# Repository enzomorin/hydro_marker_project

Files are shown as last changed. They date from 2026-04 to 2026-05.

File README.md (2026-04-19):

# hydro_marker_project

A beacon placed in small rivers to measure flooding risk, hydric stress, or normal conditions — built for the **Olympiads of Engineering Sciences**.

---

## Project overview

Each marker is a waterproof device deployed in a river. It measures water level, pressure, temperature, and battery voltage, then transmits the data via radio to a ground antenna. The antenna forwards the data to the API server, which stores it and makes it available to a dashboard and a mobile alert application.

---

## Repository structure

```
hydro_marker_project/
│
├── docs/           Documentation, source references, notes, and diagrams
│
├── app/            Dashboard application
│                   Receives data from the ground antenna, processes it,
│                   and sends it to the API. Also includes a companion app
│                   that sends alerts when a nearby marker detects potential
│                   flooding or hydric stress.
│
├── firmware/       Embedded code
│                   MCU code for the marker (sensor reading + radio transmission)
│                   and code for the ground station (receiving + forwarding frames).
│
├── hardware/       PCB design files (KiCad)
│                   Optimised circuit board for the markers — reduces electrical
│                   noise and improves efficiency.
│
├── server/         API server
│                   FastAPI + SQLite REST API that stores marker locations
│                   and all associated measurement data.
│
├── site/           Promotional website
│                   Presents the product and its specifications.
│                   Also displays live marker data and locations on a map.
│
└── tools/          Development utilities
                    Scripts and helpers that speed up development across
                    all parts of the project.
```

---

## Quick start

To run the API server locally, see [`server/README.md`](server/README.md).

---

## Tech used overview

| Component | Technology |
|---|---|
| API server | Python, FastAPI, SQLite |
| Firmware | C++ (MCU), PlatfromIO IDE |
| PCB design | KiCad |
| Dashboard | Electron, Javascript |
| Website | HTML, CSS, Javascript |

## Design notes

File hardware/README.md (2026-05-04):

# HydroVinci — PCB Design

> Compact, low-power PCB for the HydroVinci marker system. Designed in KiCad 10, built around the Seeed XIAO nRF52840 Plus.

---

## Table of Contents

- [Overview](#overview)
- [Hardware Summary](#hardware-summary)
- [Prerequisites](#prerequisites)
- [Opening the Project](#opening-the-project)
- [Manufacturing](#manufacturing)
- [Design Notes](#design-notes)
- [Tech used](#tech-used)

---

## Overview

This repository contains the full KiCad design files for the HydroVinci PCB. The board integrates all electronics required by the marker into a single compact PCB, replacing a wired prototype with a manufacturable solution.

The design targets low quiescent current for battery-powered field deployment, with switchable power rails for each peripheral.

---

## Hardware Summary

| Component | Description |
|---|---|
| MCU | Seeed XIAO nRF52840 Plus (BLE 5.0, nRF52840) |
| Power | LiPo battery input, 12V boost (Adafruit TPS61040) |
| Pressure sensor | DFRobot KIT0139 submersible 4-20mA, converted via SEN0262 |
| Environmental | AZ-Delivery GY-BME280 (temperature, humidity, pressure) |
| Hall effect | Digital Hall sensor via BSS84 high-side switch |
| Data logging | SparkFun OpenLog DEV-13712 (microSD, UART) |
| RF | CC1101 sub-GHz radio module |
| Power switching | BSS138 + BSS84 MOSFET pairs (3.3V and 12V rails) |
| Indicators | Passive buzzer, 2× tactile buttons |

---

## Prerequisites

- [KiCad](https://www.kicad.org/) `>= 10.0`

No additional dependencies. All custom symbols and footprints are included in the repository under `src/PCB/libraries/`.

---

## Opening the Project

1. Clone the repository
   ```bash
   git clone https://github.com/your-org/hydrovinci-pcb.git
   ```

2. Open KiCad and select **File → Open Project**

3. Navigate to `src/PCB/main_pcb.kicad_pro` and open it

From the KiCad project manager you can then open:
- **Schematic Editor** — for the electrical design and component wiring
- **PCB Editor** — for the physical board layout and copper routing

---

## Manufacturing

Gerber files are required to manufacture the board. To generate them from KiCad:

1. Open the PCB Editor (`main_pcb.kicad_pcb`)
2. Go to **File → Fabrication Outputs → Gerbers**
3. Select all required layers and export

The generated Gerbers can be uploaded directly to:
- [JLCPCB](https://jlcpcb.com) — recommended for low-cost prototyping
- [PCBway](https://www.pcbway.com) — recommended for higher quantities

> **Recommended specs:** 2-layer, 1oz copper.

---

## Design Notes

- All GPIO outputs include 100Ω series resistors for noise immunity
- The 12V rail (KIT0139 sensor loop) is switched via a BSS138 + BSS84 MOSFET pair — Vgs is clamped to −6V by R20 to stay within BSS84 absolute maximum ratings
- The EN pin of the boost converter is pulled to GND via R7 (100kΩ) to ensure the 12V rail is off during boot and reset
- The SEN0262 output capacitor (C14) must be rated ≥ 25V (ceramic X5R/X7R, 0805)
- I2C pull-ups R3/R4 (10kΩ) may be omitted if the BME280 module already includes them

---

## Tech used



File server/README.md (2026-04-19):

# HydroVinci — API Server

**HydroVinci API server** is an **API** secured by simple authentification system key. The **API** is based with **FastAPI** and deployed with **uvicorn** that handle the logic to store in a **SQLite database** the different markers around the world with his measure data associated:

---
 
## Table of contents
 
- [Overview](#overview)
- [Prerequisites](#prerequisites)
- [Setup](#setup)
- [Running the server](#running-the-server)
- [Authentication](#authentication)
- [Endpoints — Markers](#endpoints--markers)
- [Endpoints — Readings](#endpoints--readings)
- [Database fields](#database-fields)
- [Tech stack](#tech-stack)

---

## Overview
 
Each physical marker deployed in a river communicates sensor data to a ground antenna. The antenna receive the radio frames and pushes them to this API. The API stores everything in a local SQLite database and exposes endpoints to manage, and monitor all markers and their measurements.
 
---
 
## Prerequisites
 
- Python `>= 3.12`
- `pip`
- `git`
- `pyenv` recommended for managing Python versions on Fedora / Linux :)
---
 
## Setup
 
**1. Clone the repository**
 
```bash
git clone https://github.com/enzomorin/hydro_marker_project.git

cd hydro_marker_project/server
```
 
**2. Install Python 3.12**
 
```bash
pyenv install 3.12
pyenv local 3.12
```
 
**3. Create and activate a virtual environment**
 
```bash
virtualenv .venv             # Fedora only
python -m venv .venv
 
source .venv/bin/activate    # Linux / macOS
.venv\Scripts\activate       # Windows
```
 
**4. Install dependencies**
 
```bash
pip install -r requirements.txt
```
 
**5. Configure environment variables**
 
```bash
cp .env.example .env
```
 
Open `.env` and replace the placeholder values:
 
```env
DB_PATH=./data/markers.db
 
API_KEY=your_antenna_secret_key
ADMIN_KEY=your_admin_secret_key
 
APP_NAME=River Monitor API
DEBUG=true
```
 
> **Never commit `.env` to git** — it contains your secrets. It is already listed in `.gitignore`.
 
---
 
## Running the server
 
**Option 1 — Direct (recommended for development)**
 
```bash
python src/main.py
```
 
**Option 2 — Uvicorn directly**
 
```bash
python -m uvicorn src.main:app --host 127.0.0.1 --port 8000 --reload
```
 
The server is accessible at: `http://127.0.0.1:8000`
 
Interactive API documentation: `http://127.0.0.1:8000/docs`
 
---
 
## Authentication
 
Every request must include an `X-Api-Key` header. There are two access levels:
 
| Key | Header value | Access |
|---|---|---|
| Antenna key (`API_KEY`) | `X-Api-Key: your_antenna_key` | Read data + push readings |
| Admin key (`ADMIN_KEY`) | `X-Api-Key: your_admin_key` | Full access |
 
Implemente two key is very useful, if an attacker find a way to hack the ground station and extract the antenna_key, he can only read and push data and cannot delete markers and measurements.
 
```bash
# Example with antenna key
curl -H "X-Api-Key: your_antenna_key" http://127.0.0.1:8000/api/v1/markers/
 
# Example with admin key
curl -H "X-Api-Key: your_admin_key" http://127.0.0.1:8000/api/v1/markers/
```
 
---
 
## Endpoints — Markers
 
### `GET /api/v1/markers/`
Return the list of all active markers.
 
```bash
curl -H "X-Api-Key: your_antenna_key" \
  http://127.0.0.1:8000/api/v1/markers/
```
 
Add `?include_deleted=true` to also return soft-deleted markers.
 
---
 
### `GET /api/v1/markers/{marker_id}`
Return one specific marker by its ID.
 
```bash
curl -H "X-Api-Key: your_antenna_key" \
  http://127.0.0.1:8000/api/v1/markers/1
```
 
---
 
### `POST /api/v1/markers/` — Admin only
Register a new physical marker.
 
```bash
curl -X POST \
  -H "X-Api-Key: your_admin_key" \
  -H "Content-Type: application/json" \
  -d '{"name": "La-loire", "location": "48.8566,2.3522"}' \
  http://127.0.0.1:8000/api/v1/markers/
```
 
| Field | Type | Required | Default | Description |
|---|---|---|---|---|
| `name` | string | ✓ | — | Human-readable label |
| `location` | string | ✓ | — | GPS coordinates as `"lat,lon"` |
| `radius` | integer | | `500` | measure radius in metres |
| `is_active` | boolean | | `true` | Whether the marker is receiving data |
 
---
 
### `PATCH /api/v1/markers/{marker_id}` — Admin only
Update one or more fields of an existing marker. Only send the fields you want to change.
 
```bash
curl -X PATCH \
  -H "X-Api-Key: your_admin_key" \
  -H "Content-Type: application/json" \
  -d '{"is_active": false}' \
  http://127.0.0.1:8000/api/v1/markers/1
```
 
---
 
### `DELETE /api/v1/markers/{marker_id}` — Admin only
Move a marker to the trash (soft delete — recoverable).
 
```bash
curl -X DELETE \
  -H "X-Api-Key: your_admin_key" \
  http://127.0.0.1:8000/api/v1/markers/1
```
 
---
 
### `PUT /api/v1/markers/{marker_id}/restore` — Admin only
Recover a soft-deleted marker from the trash.
 
```bash
curl -X PUT \
  -H "X-Api-Key: your_admin_key" \
  http://127.0.0.1:8000/api/v1/markers/1/restore
```
 
---
 
### `DELETE /api/v1/markers/{marker_id}/purge` — Admin only
Permanently delete a marker and **all its readings**. This is irreversible.
 
```bash
curl -X DELETE \
  -H "X-Api-Key: your_admin_key" \
  http://127.0.0.1:8000/api/v1/markers/1/purge
```
 
---
 
## Endpoints — Readings
 
### `POST /api/v1/readings/`
Push a single sensor frame from the antenna.
 
```bash
curl -X POST \
  -H "X-Api-Key: your_antenna_key" \
  -H "Content-Type: application/json" \
  -d '{
    "marker_id": 1,
    "water_level": 1.42,
    "pressure": 1013.0,
    "temperature": 14.5,
    "battery": 3.8
  }' \
  http://127.0.0.1:8000/api/v1/readings/
```
 
| Field | Type | Required | Description |
|---|---|---|---|
| `marker_id` | integer | ✓ | ID of the marker that sent this frame |
| `recorded_at` | datetime | | When the marker took the measurement (defaults to now) |
| `water_level` | float | | Water level in metres |
| `pressure` | float | | Atmospheric pressure in hPa |
| `temperature` | float | | Water temperature in °C |
| `battery` | float | | Battery voltage in V |
| `raw_payload` | string | | Original RF frame bytes, for debugging |
 
All sensor fields are optional — a partial frame is still stored.
 
---
 
### `POST /api/v1/readings/batch`
Push multiple frames in one request. Useful when the antenna was offline and has buffered frames. Either all frames are saved or none are (atomic transaction).
 
```bash
curl -X POST \
  -H "X-Api-Key: your_antenna_key" \
  -H "Content-Type: application/json" \
  -d '[
    {"marker_id": 1, "water_level": 1.40, "temperature": 14.2},
    {"marker_id": 1, "water_level": 1.41, "temperature": 14.3},
    {"marker_id": 1, "water_level": 1.42, "temperature": 14.5}
  ]' \
  http://127.0.0.1:8000/api/v1/readings/batch
```
 
---
 
### `GET /api/v1/readings/latest?marker_id={id}`
Return the most recent reading for a specific marker. This is the endpoint to call for a live dashboard tile.
 
```bash
curl -H "X-Api-Key: your_antenna__key" \
  "http://127.0.0.1:8000/api/v1/readings/latest?marker_id=1"
```
 
---
 
### `GET /api/v1/readings/`
Return a paginated list of readings with optional filters.
 
| Parameter | Type | Description |
|---|---|---|
| `marker_id` | integer | Filter by marker |
| `since` | datetime | Lower bound on measurement time |
| `until` | datetime | Upper bound on measurement time |
| `limit` | integer (1–1000) | Max rows to return, default `100` |
| `offset` | integer | Rows to skip, for pagination |
 
```bash
# All readings for marker 1
curl -H "X-Api-Key: your_antenna_key" \
  "http://127.0.0.1:8000/api/v1/readings/?marker_id=1"
 
# Page 2 (rows 101–200)
curl -H "X-Api-Key: your_antenna_key" \
  "http://127.0.0.1:8000/api/v1/readings/?marker_id=1&limit=100&offset=100"
```
 
---
 
### `GET /api/v1/readings/{reading_id}`
Return one specific reading by its numeric ID.
 
```bash
curl -H "X-Api-Key: your_antenna_key" \
  http://127.0.0.1:8000/api/v1/readings/42
```
 
---
 
### `DELETE /api/v1/readings/{reading_id}` — Admin only
Permanently delete one reading. Use this to remove bad data from a faulty sensor or a test transmission.
 
```bash
curl -X DELETE \
  -H "X-Api-Key: your_admin_key" \
  http://127.0.0.1:8000/api/v1/readings/42
```
 
---
 
## Database fields
 
### `markers` table
 
| Field | Type | Description |
|---|---|---|
| `id` | integer | Auto-assigned primary key |
| `name` | string | Human-readable label |
| `location` | string | GPS coordinates as `"lat,lon"` |
| `radius` | integer | Alert radius in metres |
| `is_active` | boolean | Whether the marker is currently active |
| `is_deleted` | boolean | Soft-delete flag |
| `created_at` | datetime | UTC timestamp of registration |
 
### `readings` table
 
| Field | Type | Description |
|---|---|---|
| `id` | integer | Auto-assigned primary key |
| `marker_id` | integer | Foreign key → `markers.id` |
| `recorded_at` | datetime | When the marker took the measurement |
| `received_at` | datetime | When the server received the frame |
| `water_level` | float | Water level in metres |
| `pressure` | float | Atmospheric pressure in hPa |
| `temperature` | float | Water temperature in °C |
| `battery` | float | Battery voltage in V |
| `raw_payload` | string | Original RF frame for debugging |
 
---
 
## Tech used
 






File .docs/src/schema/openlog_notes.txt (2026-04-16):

et bien peut tu vérifier que le openlog en sleep consomme moins que 2mA je pense qu'il consome moins et aussi est ce que des résistance, condensateur et bobine consomme un petit peu de courant aussi ?

Très bonne question — et tu as raison de remettre ça en doute, parce que 2 mA en veille pour un OpenLog, c’est énorme pour un projet basse conso.

🔎 1) Conso réelle du OpenLog en veille

👉 Pour le SparkFun OpenLog (ATmega328 + microSD) :

📊 Valeurs typiques (issues des datasheets + retours utilisateurs)
Actif (écriture SD) : ~20–25 mA ✅ (cohérent avec ton tableau)
Idle (allumé, rien ne fait) : ~10–15 mA ❗
Sleep (optimisé) :
ATmega328 seul : ~5–50 µA
MAIS carte OpenLog complète :
régulateur
LED
carte SD

👉 En pratique :

Carte SD seule : ~100 µA à plusieurs mA selon état 😬
Régulateur + LED → fuite continue
⚠️ Conclusion réaliste

👉 Un OpenLog “stock” :

❌ pas conçu pour ultra low power
✔️ conso typique en veille réelle :
👉 ~1 mA à 5 mA (parfois pire)

👉 Donc :
💬 Ton “2 mA” est plutôt crédible, voire optimiste.

🛠️ Si tu veux vraiment réduire :
couper alimentation via transistor/MOSFET ✅ (meilleure solution)
enlever LED
utiliser une SD low-power
ou remplacer par autre chose (ex: FRAM)
⚡ 2) Est-ce que résistances, condensateurs, bobines consomment ?

👉 Réponse courte :
✔️ oui, mais pas toujours de la même façon

🔌 Résistance

👉 Consomme TOUJOURS si courant passe

Formule :
👉 I = V / R

Exemple :

3.3V avec résistance 10kΩ
→ 3.3 / 10000 = 0.33 mA

⚠️ Donc :

pull-up / pull-down mal choisis → grosse perte !
⚡ Condensateur

👉 Ne consomme pas en régime stable

consomme uniquement pendant charge/décharge
fuite très faible (µA ou moins)

✔️ Donc négligeable dans ton cas

🌀 Bobine (inductance)

👉 Idem :

pas de conso directe
MAIS :
résistance interne (R série)
pertes dans convertisseurs (buck/boost)
⚠️ Les VRAIS pièges en basse conso

Ce qui consomme vraiment sans qu’on s’en rende compte :

🔴 1. Régulateur de tension
peut consommer 10 µA à 1 mA
👉 énorme sur 3 mois
🔴 2. LED
1 LED = 1 à 5 mA 😬
🔴 3. Pull-up trop faibles
ex : 1kΩ → gaspillage massif
🔴 4. Modules non coupés
capteurs ou radio “en veille” → souvent trompeur
✅ Conclusion claire

👉 OpenLog :

❌ pas basse conso
✔️ ton estimation ~2 mA est crédible

👉 Composants passifs :

résistance → OUI consomme
condensateur → quasi rien
bobine → indirect
💡 Reco pour ton projet

👉 Pour tenir 3 mois facilement :

❌ éviter OpenLog alimenté en continu
✔️ couper alimentation modules (MOSFET)
✔️ viser conso sleep < 10 µA total
✔️ utiliser résistances ≥ 100kΩ si possible

Si tu veux, je peux te faire :
👉 un schéma optimisé ultra low power (avec coupure des modules)
👉 ou recalculer autonomie avec TON montage exact (très utile)

qu'elles sont tout les types de transistor et leur usage dans un cas précis et aussi mon openlog je peux le couper avec un MOSFET mais avec le serial et tout et l'inisialisation de la carte sd à l'allumage sa ne va pas faire n'importe quoi ?

Bonne question — tu touches exactement aux deux points clés : choix du transistor et coupure propre d’un module comme l’OpenLog. On va faire ça clairement et sans blabla inutile.

🔌 1) Les types de transistors (et quand les utiliser)
🧱 1. BJT (bipolaires)
Types :
NPN
PNP
👉 Usage typique :
Commutation simple
Amplification analogique
✔️ Exemple concret :
Allumer une LED
Piloter un petit module
⚠️ Inconvénients :
Consomme du courant en base
Moins efficace que MOSFET

👉 En basse conso → pas idéal

⚡ 2. MOSFET (les plus importants pour toi)
Types :
N-MOS (canal N)
P-MOS (canal P)
🔵 N-MOS

👉 Sert à couper la masse (low-side switch)

✔️ Avantages :
Très efficace
Facile à piloter (GPIO)
❌ Problème :
Le module reste relié au +
→ peut créer des comportements bizarres (retours par IO)
🔴 P-MOS

👉 Sert à couper le + (high-side switch)

✔️ Avantages :
Coupe complètement l’alimentation
Propre pour modules (comme OpenLog)
❌ Plus complexe à piloter
💡 Conclusion pratique :

👉 Pour ton cas :

❌ N-MOS → risqué avec UART
✔️ P-MOS → meilleur choix
🧠 3. Autres types (moins utiles ici)
🟡 Darlington
Très fort gain
Mais chute de tension élevée
👉 pas adapté basse conso
🟢 IGBT
Puissance (moteurs, industrie)
👉 inutile ici
⚠️ 2) Couper l’OpenLog avec MOSFET + UART

👉 Ta question est excellente :

“est-ce que ça va faire n’importe quoi avec le serial et la SD ?”

👉 Réponse courte :

✔️ NON, si c’est bien fait
❌ OUI, si mal câblé

🚨 Les vrais problèmes possibles
🔴 1. Retour de courant par UART

Quand OpenLog est OFF :

TX/RX peuvent alimenter la carte par les pins 😬

👉 Résultat :

faux démarrage
conso fantôme
comportement instable
🔴 2. Initialisation SD

À chaque ON :

la carte SD redémarre
OpenLog reboot

👉 Donc :
✔️ prévoir un délai (~100–500 ms)
✔️ réinitialiser la communication série

✅ Solution propre (recommandée)
✔️ 1. Utiliser un P-MOS (high-side)

Schéma logique :

Batterie + ── P-MOS ── OpenLog VCC
                |
              GPIO
✔️ 2. Protéger les lignes UART
Méthodes :
🟢 Option A (simple)
mettre résistance série (~10k) sur TX/RX
🟢 Option B (propre)
mettre MOSFET ou buffer tri-state
🟢 Option C (très simple et efficace)

👉 Mettre les GPIO en INPUT quand OpenLog est OFF

✔️ 3. Séquence logicielle

Quand tu veux écrire :

Activer MOSFET → ON
Attendre ~200 ms
Init Serial
Envoyer données
Attendre fin écriture (~50–100 ms)
Couper MOSFET
🧪 Est-ce que ça marche en pratique ?

👉 Oui, c’est une technique ultra classique en IoT basse conso

Utilisée pour :

cartes SD
capteurs gourmands
modules radio
⚠️ Point critique

👉 OpenLog n’est pas fait pour ça à la base

Donc :

parfois instable au boot
dépend de la carte SD
💡 Alternative BEAUCOUP plus propre

Si tu veux un système fiable :

✔️ Option 1
écrire directement depuis le nRF52840 sur SD
✔️ Option 2
utiliser mémoire FRAM (ultra basse conso)
✅ Conclusion

👉 Transistors :

MOSFET > BJT pour ton projet
P-MOS = meilleur choix pour couper alimentation

👉 OpenLog :

✔️ possible de le couper
⚠️ attention UART + timing
✔️ ajouter résistances ou mettre GPIO en entrée

Si tu veux, je peux :
👉 te dessiner un schéma exact (propre et safe)
👉 ou te donner un montage ultra optimisé pour tenir 1 an+ de batterie

parle moi plus en détail des option B C et D

Parfait, là on rentre dans le concret 👍
Je vais détailler proprement les solutions pour éviter les retours de courant via l’UART quand tu coupes l’OpenLog.

⚠️ Rappel rapide du problème

Quand ton OpenLog est OFF mais relié au microcontrôleur :

les broches TX/RX peuvent injecter du courant
→ le module peut se “semi-alimenter”
→ bugs + conso fantôme 😬
🟢 Option B — Buffer / Tri-state (solution propre)
💡 Principe

Tu interposes un composant entre MCU et OpenLog :

👉 Quand OpenLog OFF → lignes déconnectées électriquement

🔧 Composants typiques
74HC125
74LVC1T45
⚙️ Fonctionnement
Le buffer a une entrée “enable”
Quand désactivé → sortie = haute impédance (comme si débranché)
✔️ Avantages
Très propre électriquement
Aucun retour de courant
Stable à 100%
❌ Inconvénients
Ajoute un composant
Un peu plus complexe
🧠 Quand utiliser

👉 Projet sérieux / production / basse conso optimisée

🟢 Option C — GPIO en mode INPUT (solution simple et efficace)
💡 Principe

Quand OpenLog est OFF :

👉 tu mets :

TX → INPUT
RX → INPUT
⚙️ Pourquoi ça marche
Une entrée = très haute impédance
Donc presque aucun courant ne passe
✔️ Avantages
Ultra simple
Pas de composant
Très utilisé en pratique
❌ Limites
Pas aussi “parfait” qu’un buffer
Peut rester micro-fuites (mais souvent négligeables)
🧠 Exemple de séquence
// Avant extinction OpenLog
pinMode(TX, INPUT);
pinMode(RX, INPUT);

// couper MOSFET

Puis au réveil :

// rallumer OpenLog
// attendre 200 ms

pinMode(TX, OUTPUT);
pinMode(RX, INPUT);
Serial.begin(9600);
🧠 Quand utiliser

👉 90% des projets low power → suffisant

🟢 Option D — Résistances série (solution “semi-propre”)
💡 Principe

Tu ajoutes une résistance sur chaque ligne UART :

4.7kΩ à 10kΩ typiquement
⚙️ Ce que ça fait
limite le courant si retour
évite d’alimenter fortement le module
✔️ Avantages
Très simple
Pas cher
améliore déjà beaucoup la situation
❌ Inconvénients
Ne bloque PAS totalement le courant
juste une limitation
🧠 Exemple
MCU TX ──[10k]── RX OpenLog
MCU RX ──[10k]── TX OpenLog
🧠 Quand utiliser

👉 en complément d’une autre méthode

🏆 Comparaison rapide
Solution	Efficacité	Complexité	Recommandé
Buffer (B)	⭐⭐⭐⭐⭐	Moyen	Projets critiques
GPIO INPUT (C)	⭐⭐⭐⭐	Très simple	✅ meilleur choix
Résistance (D)	⭐⭐⭐	Très simple	En complément
💡 Ce que je te recommande (concret)

👉 Pour TON projet :

✔️ Option C + D combinées

GPIO en INPUT quand OFF
résistances 10k sur TX/RX

👉 = simple + fiable + basse conso

⚠️ Petit détail important

Même avec tout ça :
👉 toujours prévoir :

délai après allumage (200–500 ms)
réinitialisation série
parfois 1er message ignoré
✅ Conclusion
Option B → parfaite mais plus complexe
Option C → meilleur compromis
Option D → sécurité en plus

👉 combo C + D = 🔥 parfait pour toi

🔧 🎯 OBJECTIF

Passer de :

4.8 kbps → 2.4 kbps
garder BW ~58 kHz
garder GFSK
ajuster deviation

👉 Sur CC1101 ça joue ici :

MDMCFG4
MDMCFG3
DEVIATN

(Car data rate = combinaison MDMCFG4/3 )

🧩 ✅ MODIFICATIONS À FAIRE
🔵 1. DATA RATE (LE PLUS IMPORTANT)
❌ TON CODE ACTUEL
writeReg(Config::MDMCFG4,  0xF5);
writeReg(Config::MDMCFG3,  0x83); // ~4.8 kbps
✅ NOUVELLE CONFIG (≈ 2.4 kbps)
writeReg(Config::MDMCFG4,  0xF6);
writeReg(Config::MDMCFG3,  0x83);
🔵 2. DEVIATION (petit ajustement)
❌ actuel
writeReg(Config::DEVIATN,  0x35); // ~25 kHz
✅ recommandé (un peu plus propre pour 2.4 kbps)
writeReg(Config::DEVIATN,  0x34); // ~20–22 kHz
🟢 3. LE RESTE → TU NE TOUCHES PAS

✔️ déjà optimal :

writeReg(Config::MDMCFG2,  0x13); // GFSK ✔️
writeReg(Config::MDMCFG1,  0x22); // OK
writeReg(Config::MDMCFG0,  0xF8); // spacing OK

✔️ BW ~58 kHz déjà bon

🧠 💡 EXPLICATION CLAIRE
📉 1. Pourquoi MDMCFG4 change ?

Dans CC1101 :

MDMCFG4 → exponent (DRATE_E)
MDMCFG3 → mantisse (DRATE_M)

👉 formule interne :

𝑅
𝑑
𝑎
𝑡
𝑎
=
(
256
+
𝐷
𝑅
𝐴
𝑇
𝐸
𝑀
)
⋅
2
𝐷
𝑅
𝐴
𝑇
𝐸
𝐸
⋅
𝑓
𝑜
𝑠
𝑐
2
28
R
data

=
2
28
(256+DRATE
M

)⋅2
DRATE
E

⋅f
osc

👉 donc :

passer 0xF5 → 0xF6
➡️ divise presque par 2 le débit
📡 2. Pourquoi c’est mieux

👉 ↓ débit = ↑ sensibilité

4.8 kbps → ~ -112 dBm
2.4 kbps → ~ -115 dBm

➡️ +3 dB ≈ +40% portée

📶 3. Pourquoi ajuster la déviation

👉 règle RF :

deviation ≈ data_rate × 8 à 10

4.8 kbps → ~25 kHz ✔️
2.4 kbps → ~20 kHz mieux

➡️ meilleure stabilité + moins d’erreurs

⚡ IMPACT RÉEL
Paramètre	Avant	Après
Débit	4.8 kbps	2.4 kbps
Sensibilité	-112 dBm	-115 dBm
Portée	~400 m	~700 m
Conso	identique	identique
🚀 BONUS (très important)

👉 avec ton usage (1 envoi toutes 12h) :

➡️ temps TX double
➡️ MAIS énergie ≈ identique
➡️ portée ↑ énormément

👉 donc c’est un upgrade gratuit

🧾 VERSION FINALE (copier-coller)
// Modem config optimisé longue portée
writeReg(Config::MDMCFG4,  0xF6); // ↓ data rate
writeReg(Config::MDMCFG3,  0x83); // mantisse inchangée
writeReg(Config::MDMCFG2,  0x13); // GFSK
writeReg(Config::MDMCFG1,  0x22);
writeReg(Config::MDMCFG0,  0xF8);

// Deviation ajustée
writeReg(Config::DEVIATN,  0x34);
🧠 CONCLUSION

👉 tu viens de gagner :

portée ++
robustesse ++
sans coût batterie

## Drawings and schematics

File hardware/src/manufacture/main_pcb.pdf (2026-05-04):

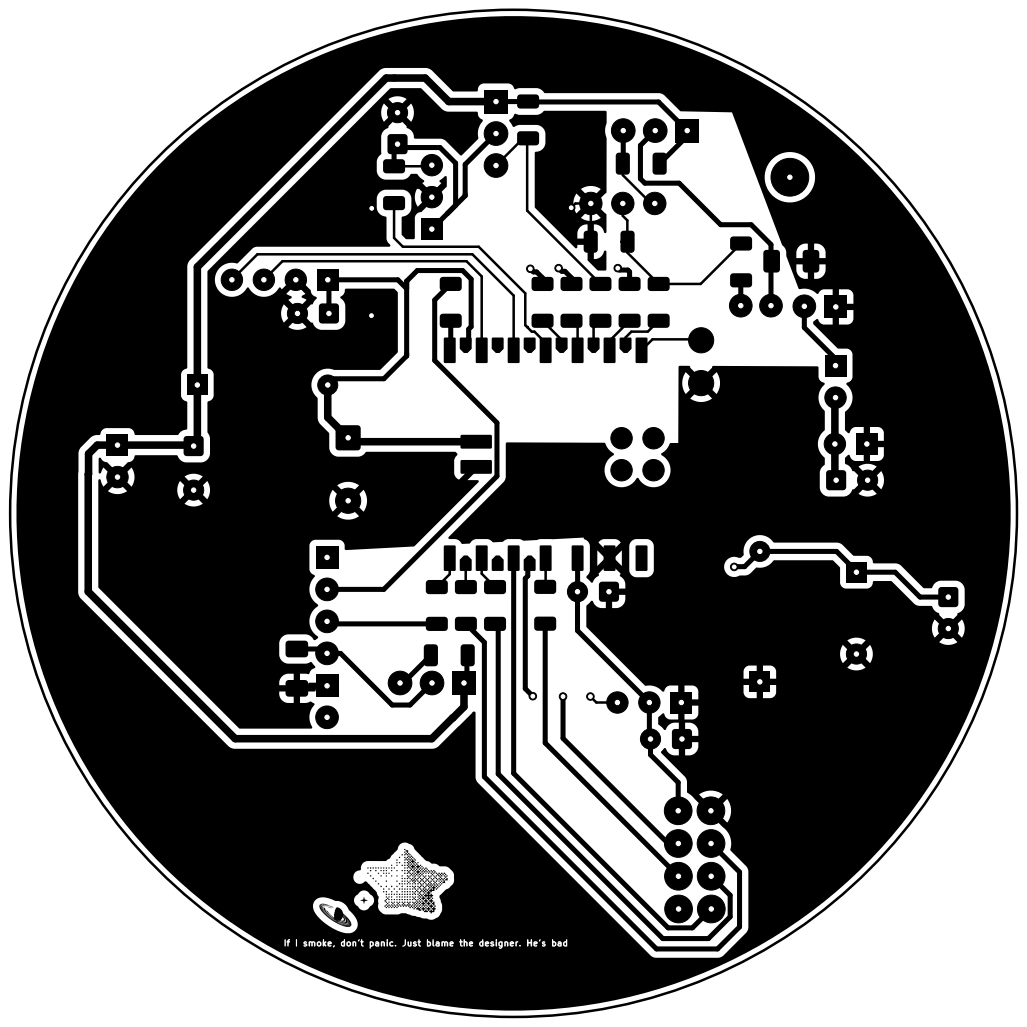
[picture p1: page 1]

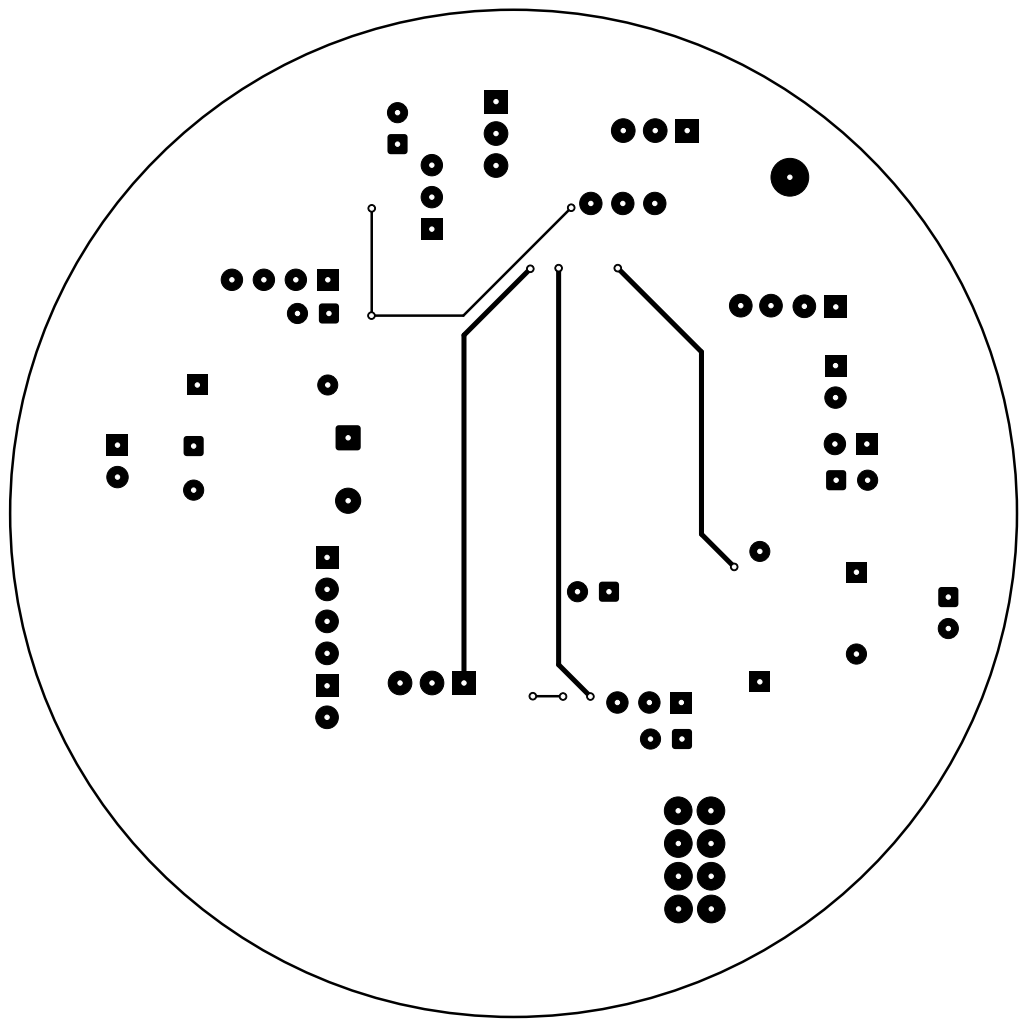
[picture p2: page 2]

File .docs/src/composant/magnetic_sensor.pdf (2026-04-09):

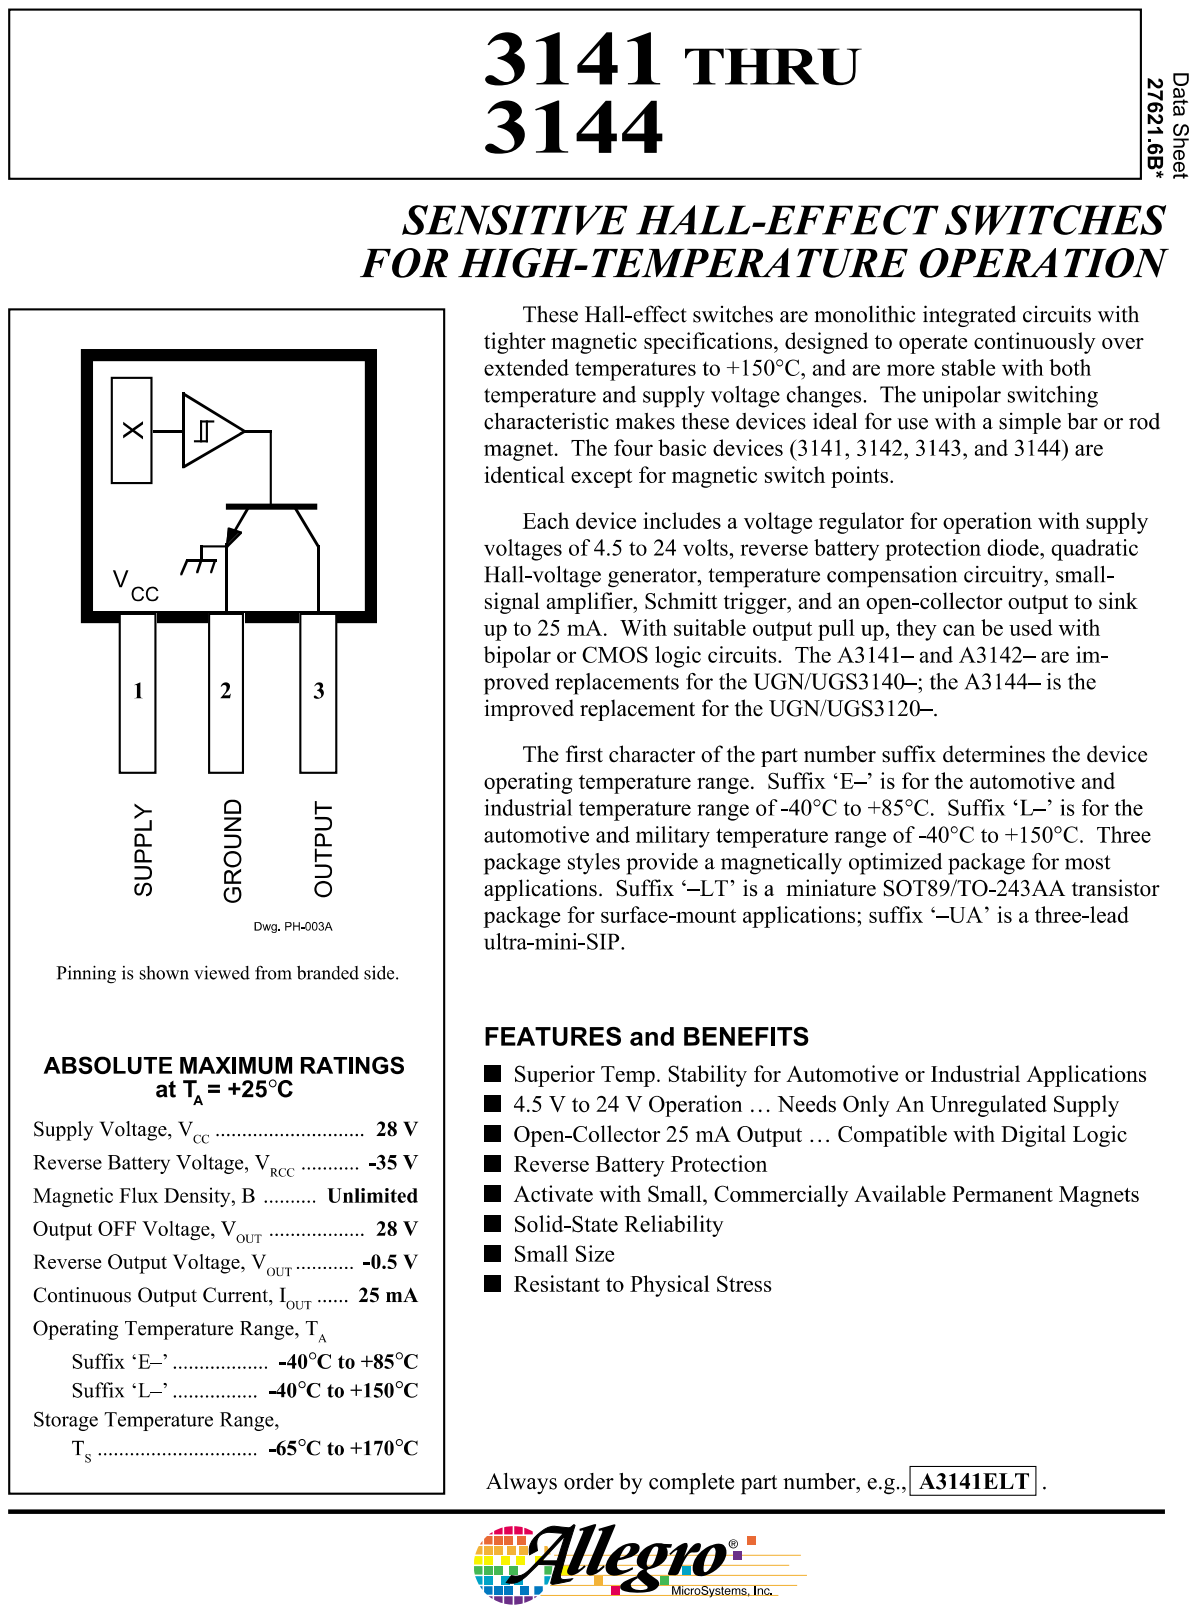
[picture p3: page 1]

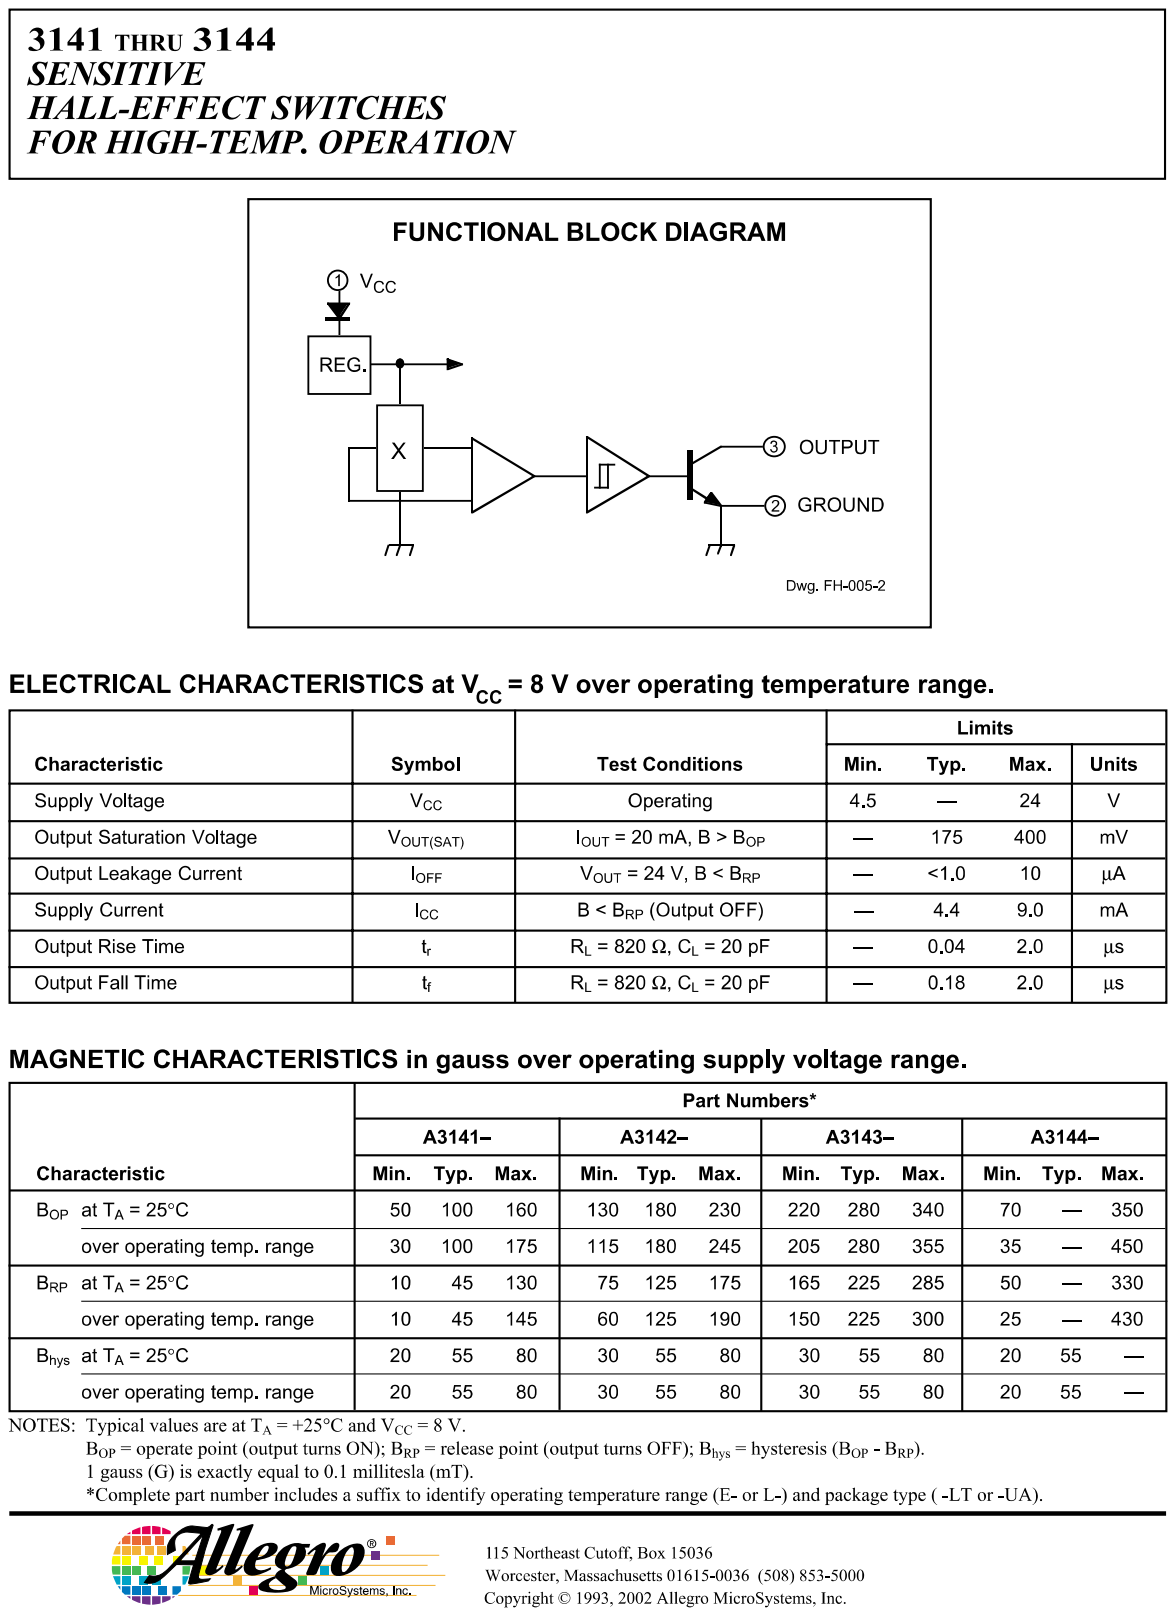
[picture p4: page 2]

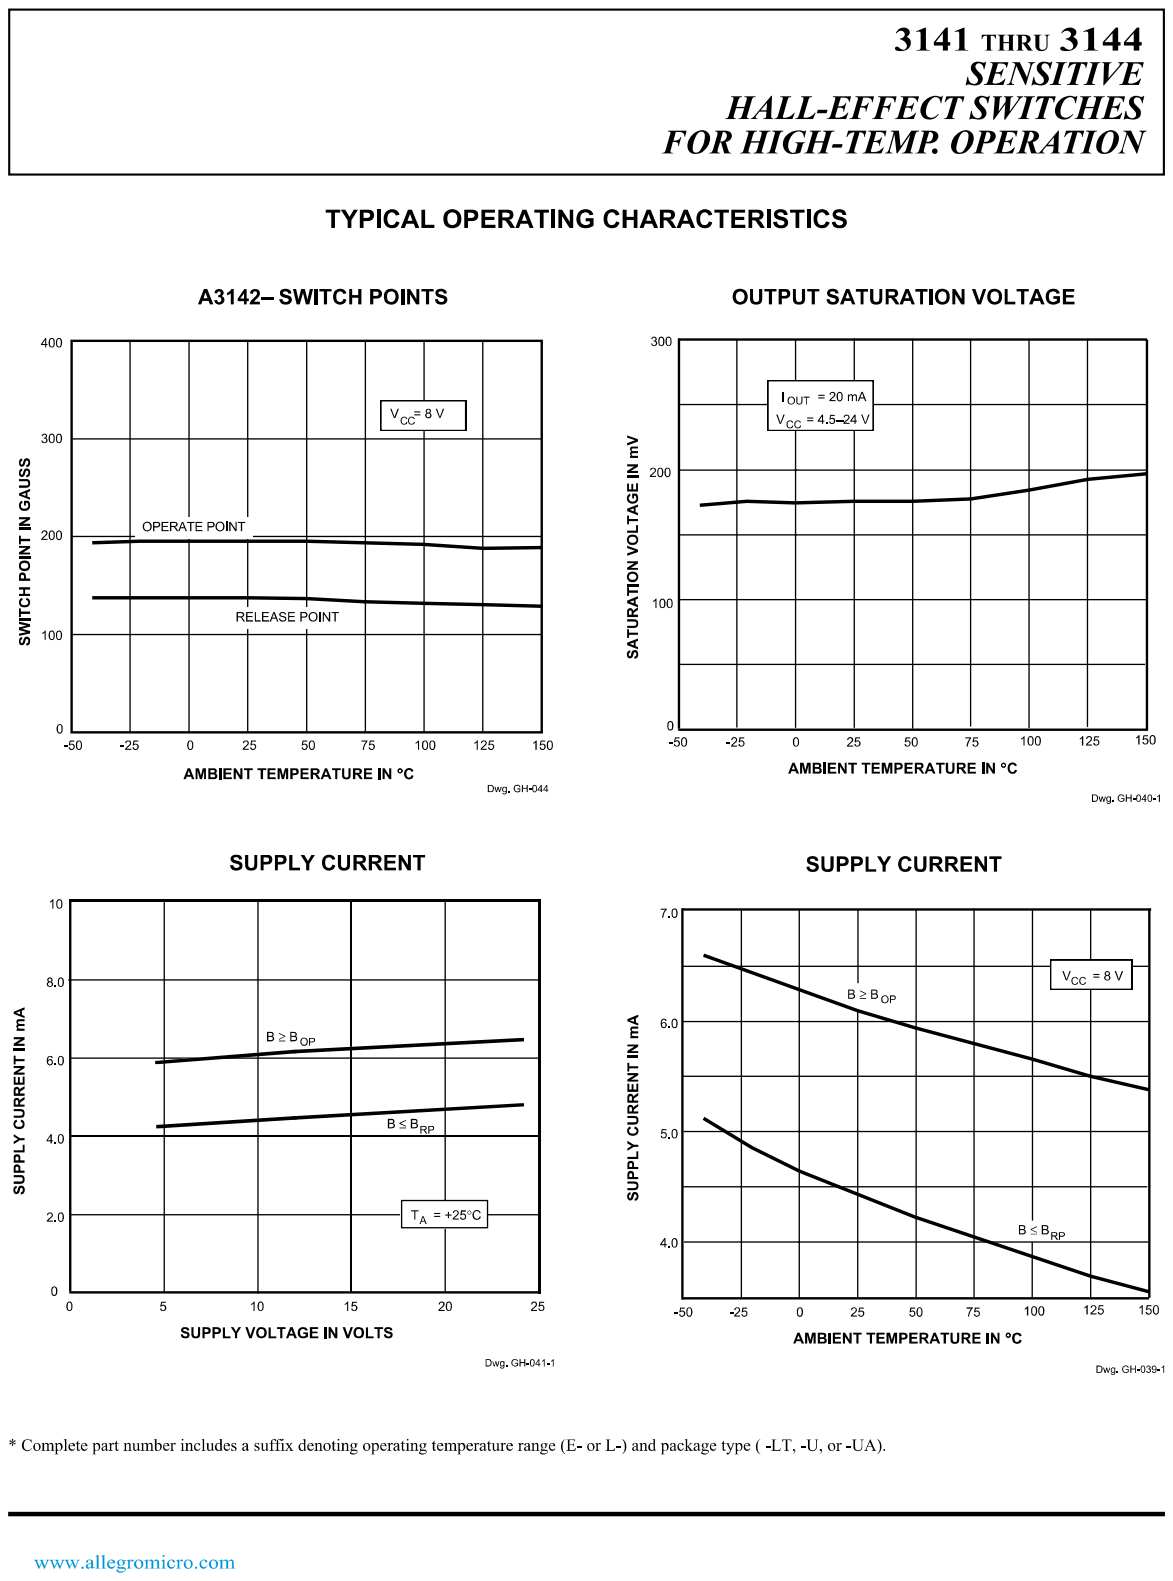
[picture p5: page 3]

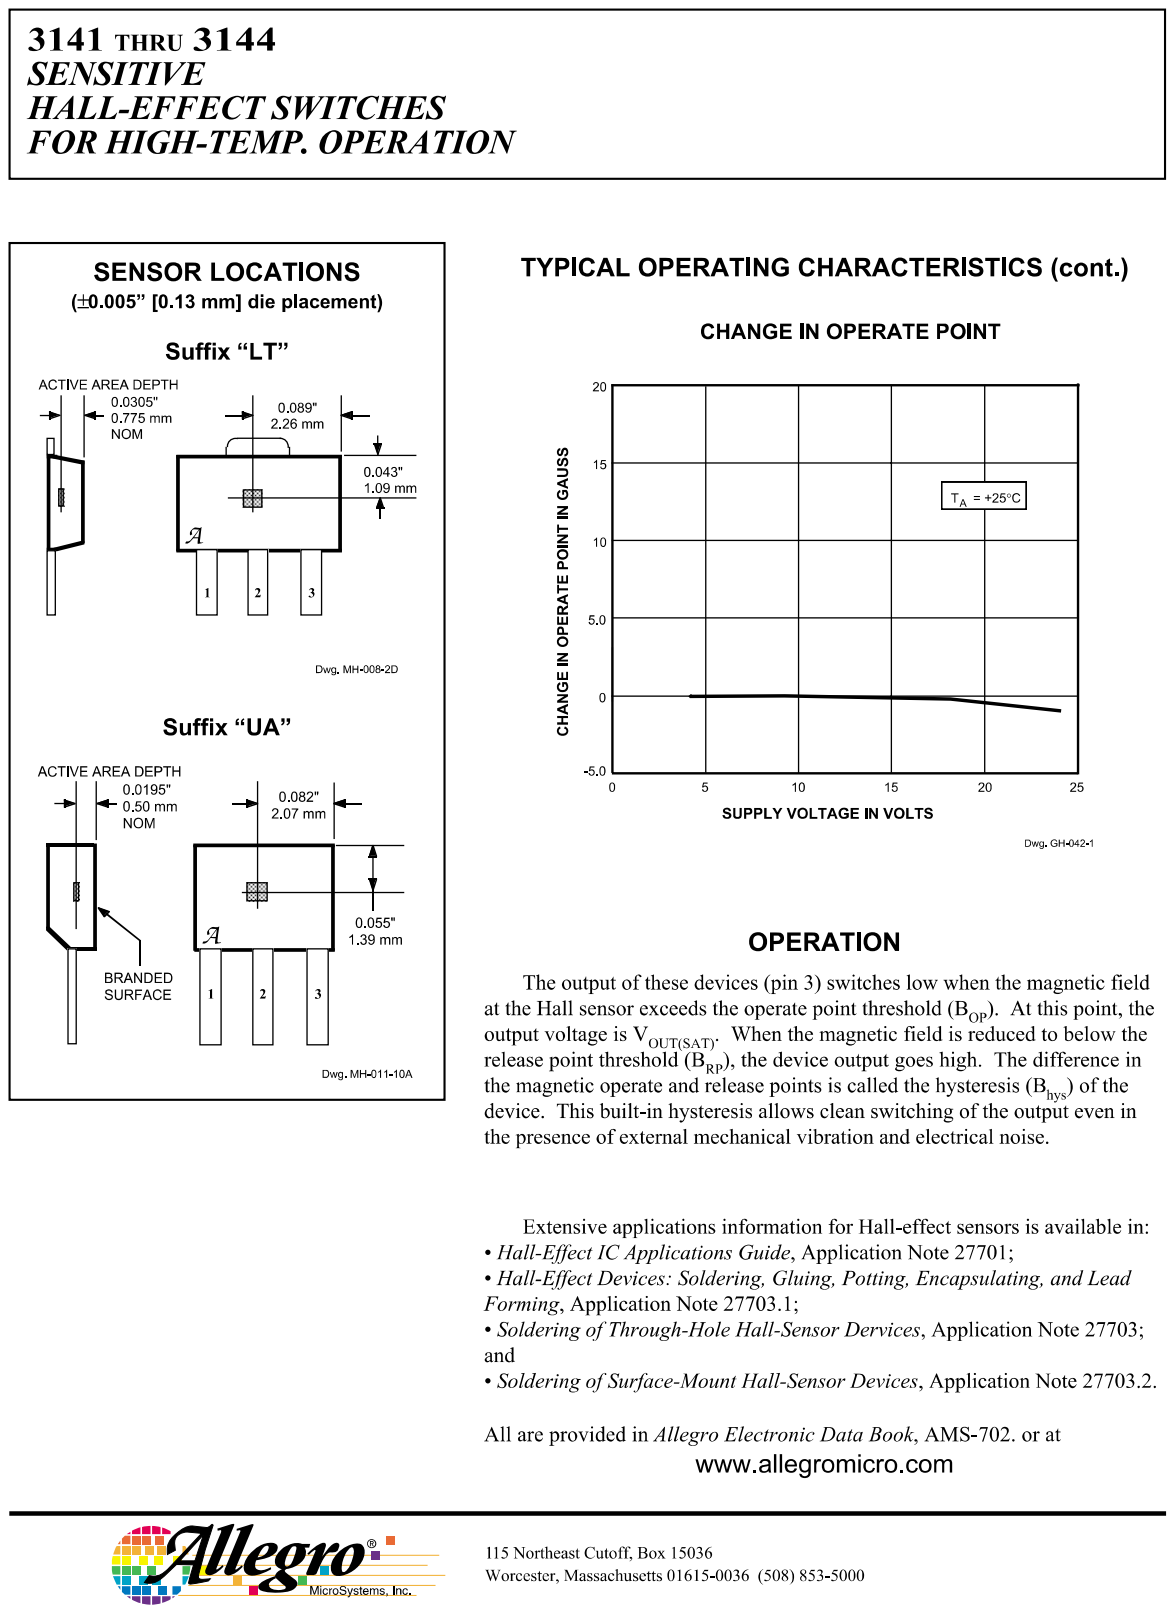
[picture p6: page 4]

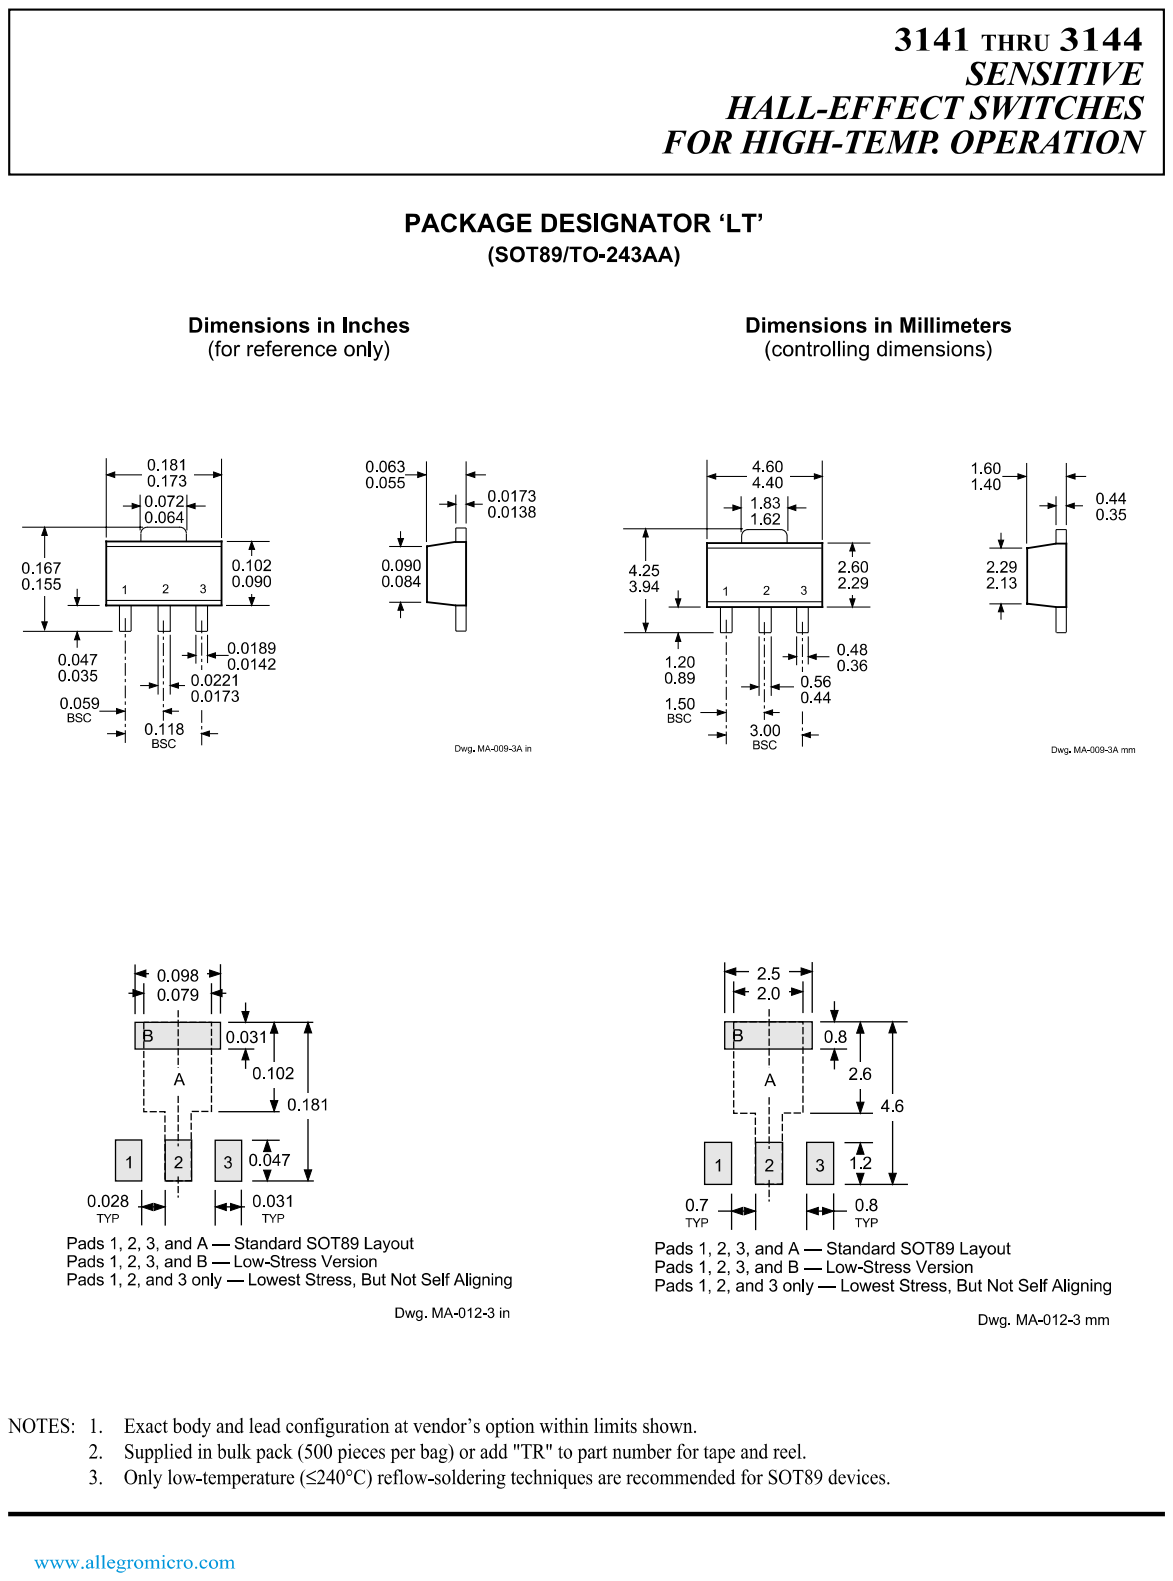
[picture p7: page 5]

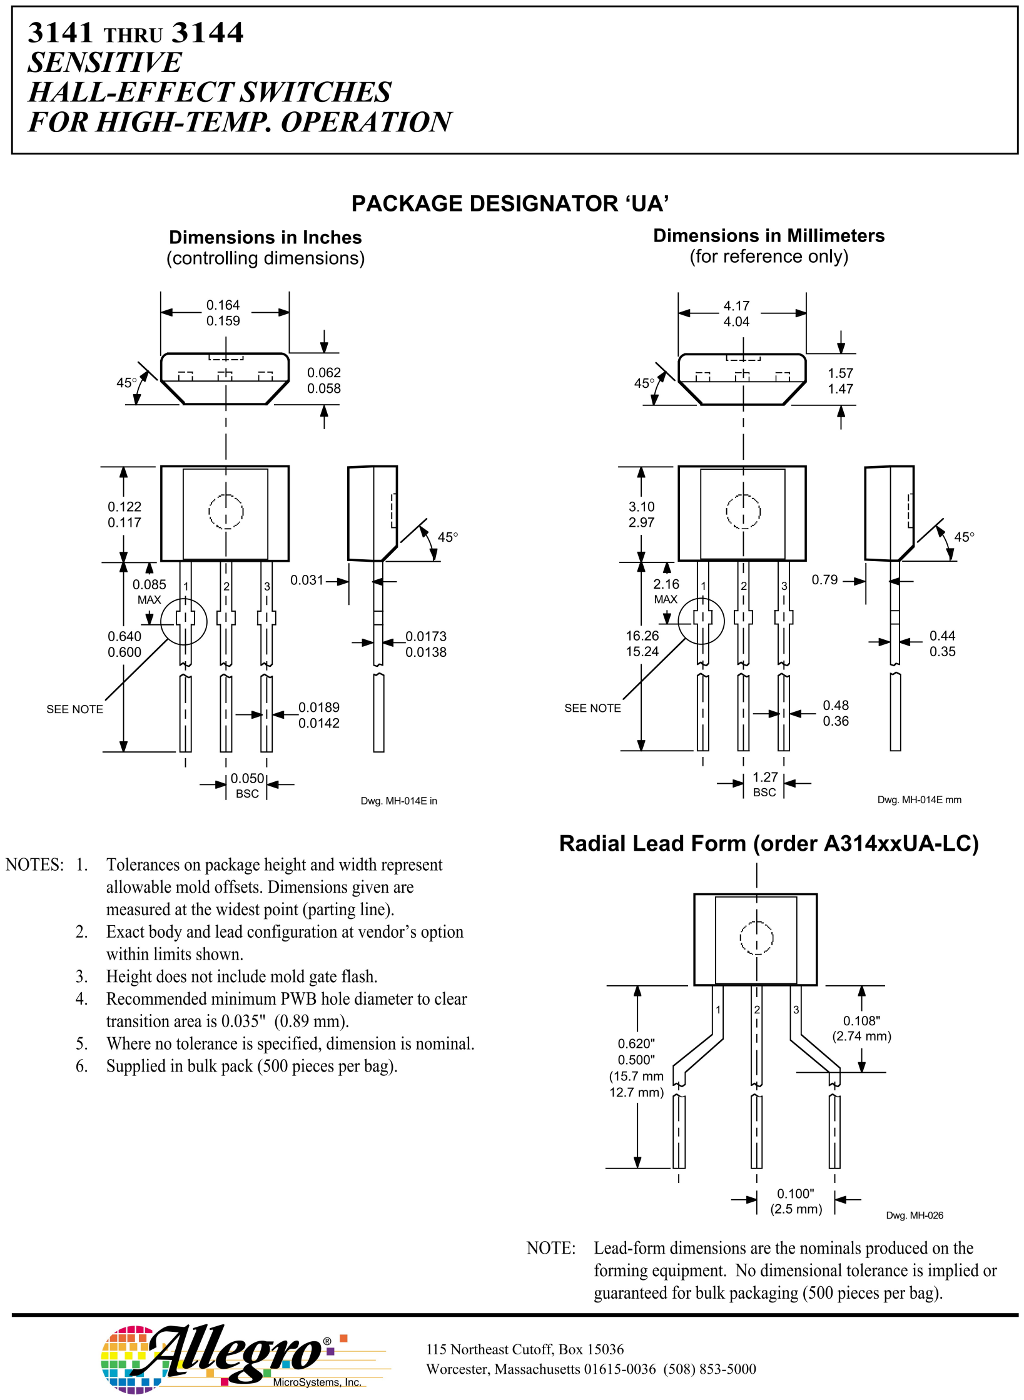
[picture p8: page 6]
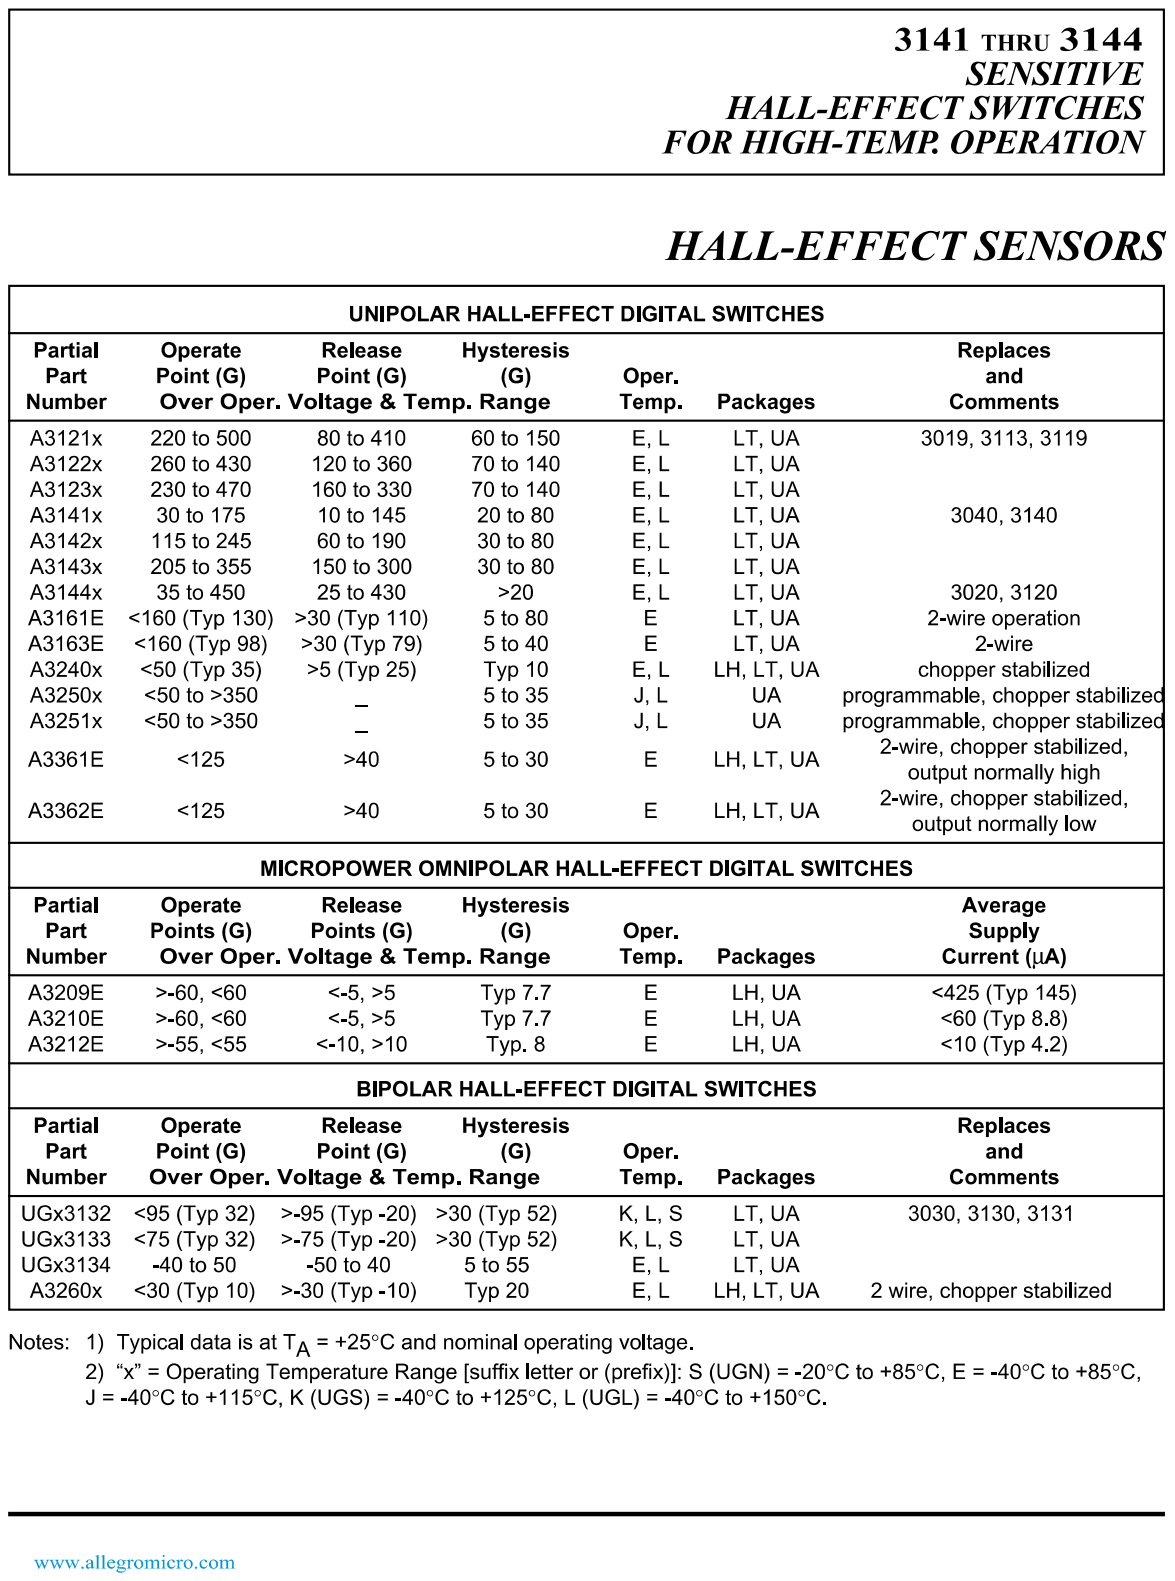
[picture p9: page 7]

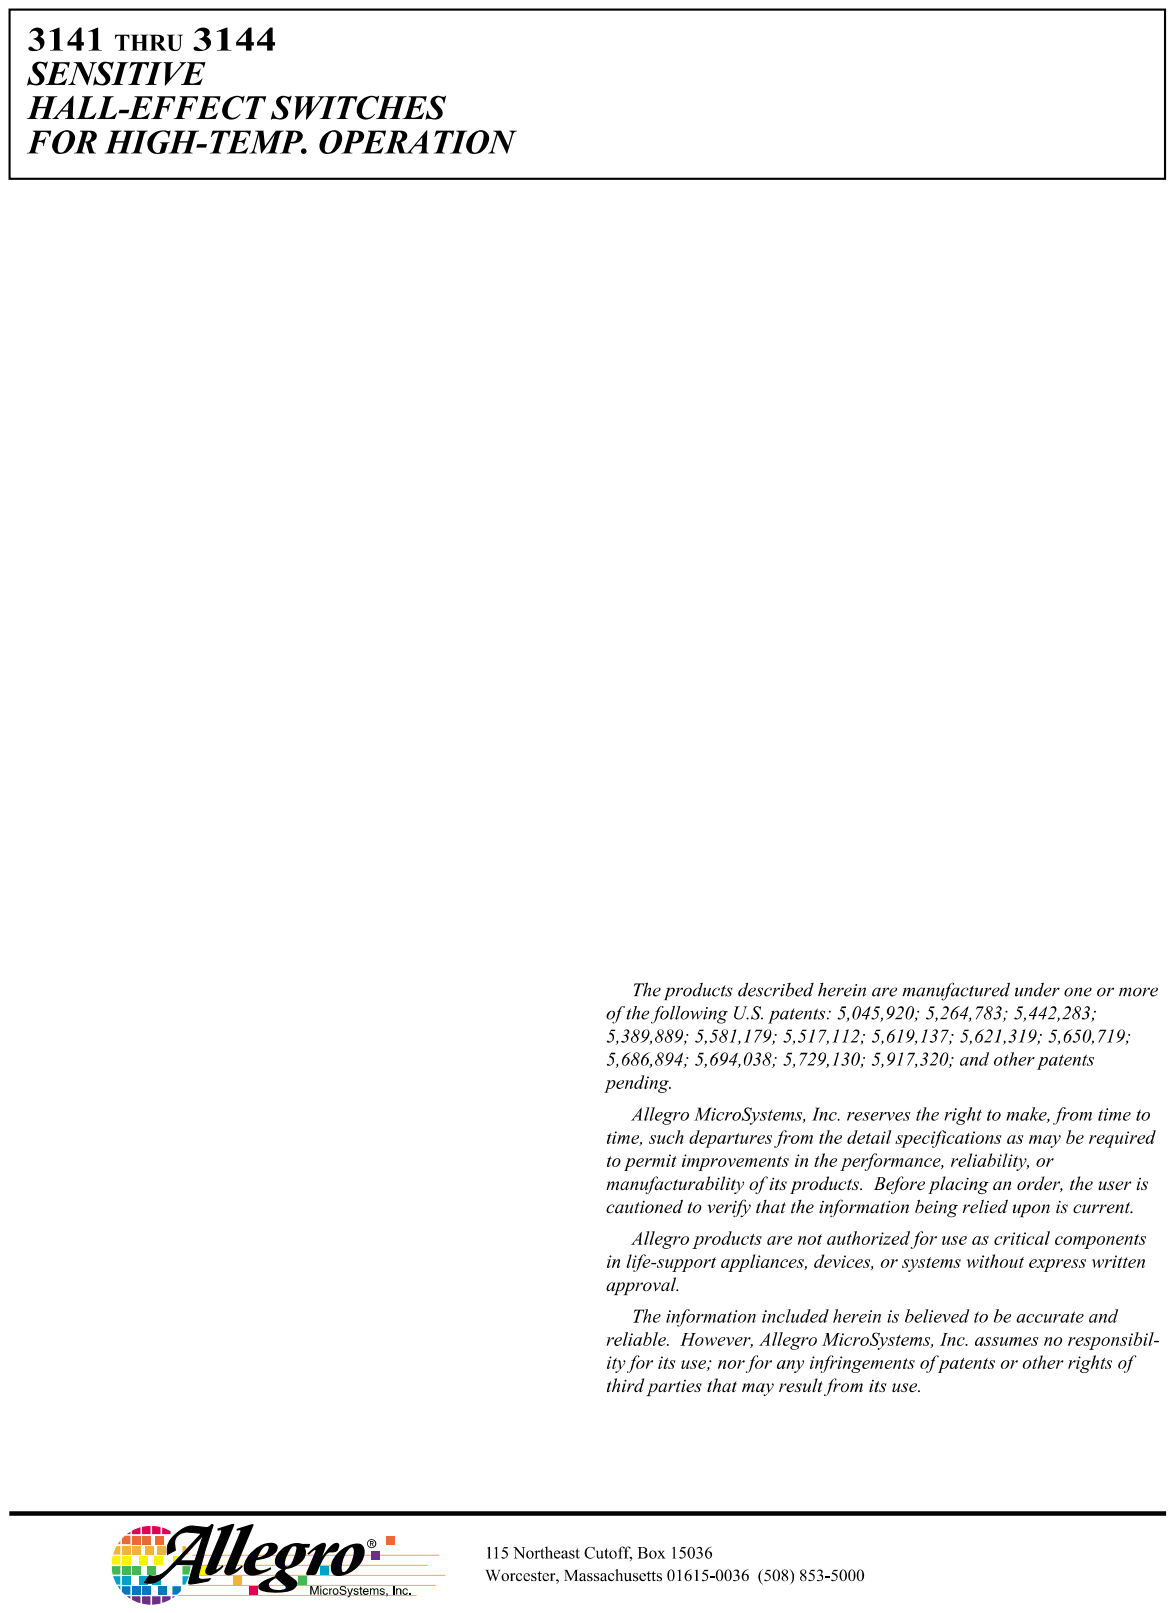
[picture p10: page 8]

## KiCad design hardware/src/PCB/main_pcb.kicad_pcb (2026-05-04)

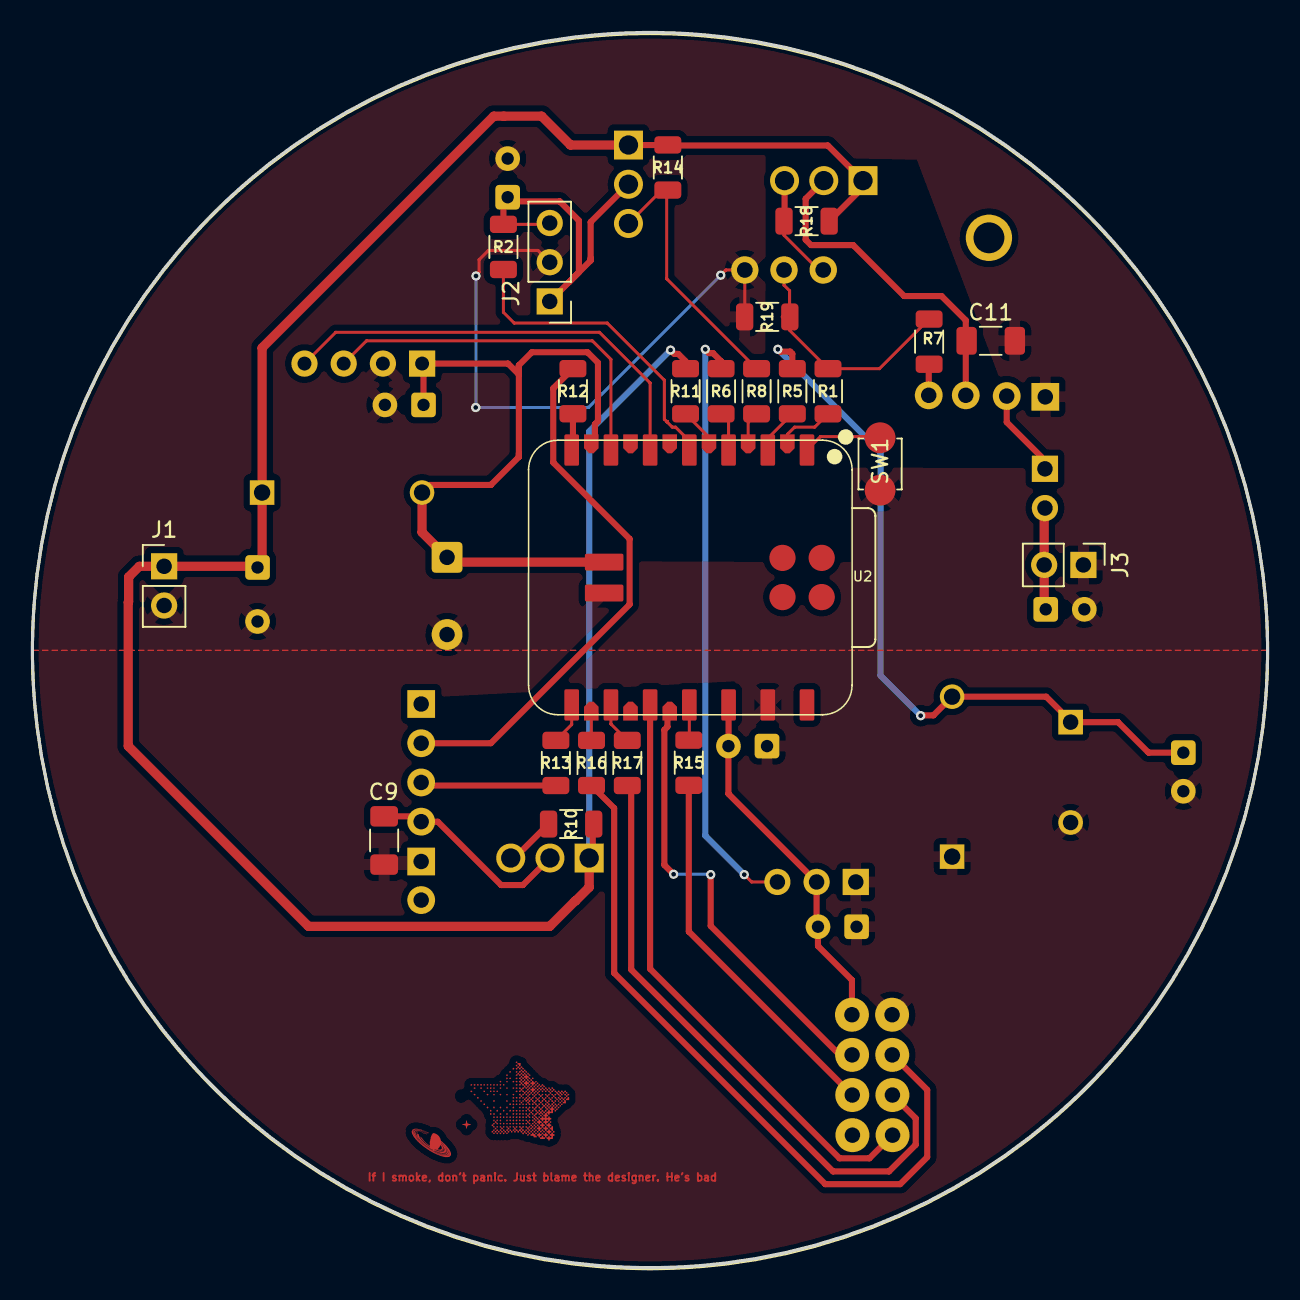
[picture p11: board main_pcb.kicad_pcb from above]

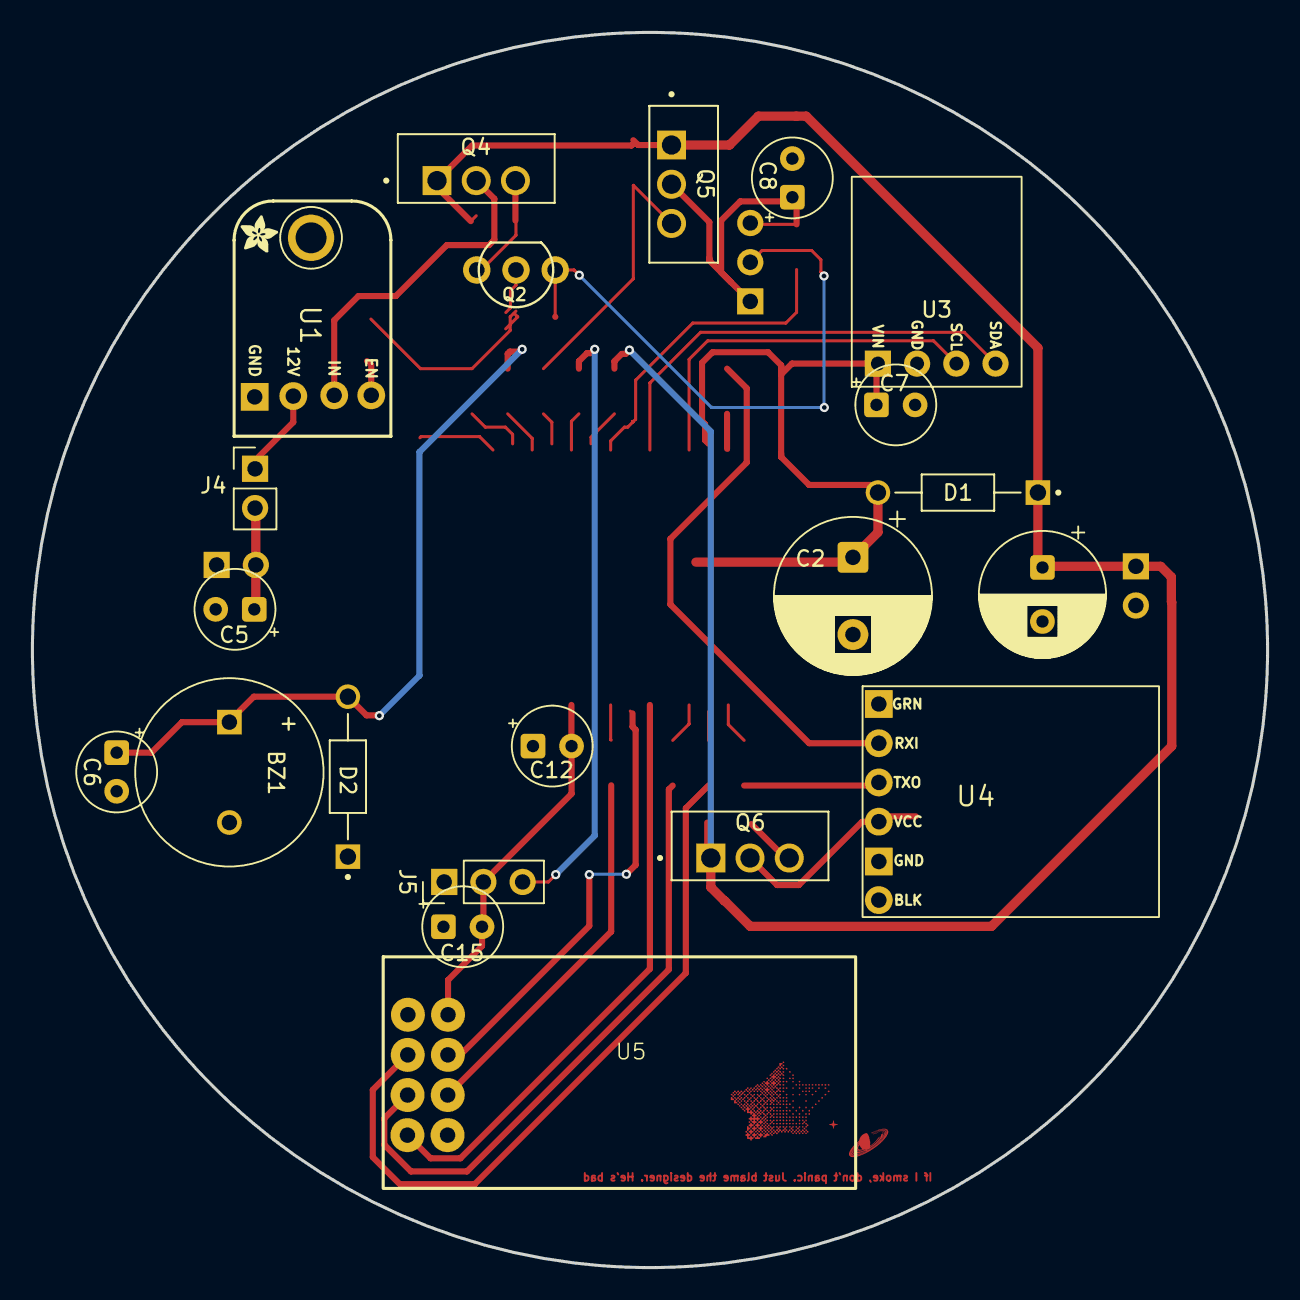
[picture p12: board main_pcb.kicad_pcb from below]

Board: 2 copper layers, 80.0 x 80.0 mm, 44 parts (21 on the bottom side), 30 nets.

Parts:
BZ1: Buzzer; MagneticBuzzer_ProSignal_ABT-410-RC
C2: 47 µF - électrolytique; CP_Radial_D10.0mm_P5.00mm
C5, C6, C7, C8, C12, C15: 100 nF - céramique; CP_Radial_Tantal_D5.0mm_P2.50mm
C9, C11: 100 nF - céramique; C_1206_3216Metric_Pad1.33x1.80mm_HandSolder
C17: 220 µF - électrolytique; CP_Radial_D8.0mm_P3.50mm
D1: 1N5819; DIOAD1036W78L470D235
D2: fr107; DIOAD1036W78L470D235
J1: Batt; PinHeader_1x02_P2.54mm_Vertical
J2: Hall_sensor; PinHeader_1x03_P2.54mm_Vertical
J3: Pressure_sensor; PinHeader_1x02_P2.54mm_Vertical
J4: Pressure_pins; PinHeader_1x02_P2.54mm_Vertical
J5: converter_pins; PinHeader_1x03_P2.54mm_Vertical
Q2: BS170; TO92
Q4, Q5, Q6: IRF9530; TRANS_IRF9530
R1, R5, R8, R11, R12, R13: 100 Ω; R_1206_3216Metric
R2: 10k Ω; R_1206_3216Metric
R6: 1k Ω; R_1206_3216Metric
R7, R10, R14, R18, R19: 100k Ω; R_1206_3216Metric
R15, R16, R17: 33 Ω; R_1206_3216Metric
SW1: Button; SW_SPST_B3U-1000P
U1: Adafruit_TPS61040_5644
U2: XIAO-nRF52840-Plus-SMD
U3: BME280
U4: OpenLog
U5: CC1101

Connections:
+3.3V: BZ1.1 (+), C2.1, C6.1, C7.1, C8.1, C9.1, C11.1, C12.2, C15.2, C17.1, D1.A, D1.C, D2.A, J1.1, J2.1, J2.3, J5.2, Q4.1 (G), Q4.2 (S), Q5.2 (S), Q5.3 (D), Q6.2 (S), Q6.3 (D), R2.1, R5.1, R10.2, R14.2, R18.2, U1.1 (vcc), U2.12 (3V3), U2.28, U3.1 (vcc), U4.4 (vcc), U5.2 (VCC)
+12V: C5.1, J3.2, J4.1, J4.2, U1.3 (Vout)
/Button: SW1.1 (A), U2.1 (P0.02_A0_D0)
/Hall: R2.2, U2.4 (P0.29_A3_D3)
/MISO1: U2.10 (P1.14_D9_MISO), U5.7 (MISO)
/MOSFET2: Q5.1 (G), R8.1, R14.1
/MOSFET3: Q6.1 (G), R10.1, R11.1
/MOSI1: R15.1, U5.6 (MOSI)
/PressureA: J5.3, R6.1
/RF_CSN: U2.23 (P1.07_D19_MOSI1), U5.4 (CSN)
/RF_GDO0: R16.1, U5.3 (GDO0)
/SCK1: R17.1, U5.5 (SCK)
/SCL1: U2.6 (P0.05_A5_D5_SCL), U3.3 (scl)
/SDA1: U2.5 (P0.04_A4_D4_SDA), U3.4 (sda)
/SD_RX: R12.1, U4.2 (rxi)
/SD_TX: R13.1, U4.3 (txo)
/Transistor+: Q2.3 (D), Q4.3 (D), R18.1
GND: BZ1.2 (-), C2.2, C5.2, C6.2, C7.2, C8.2, C9.2, C11.2, C12.1, C15.1, C17.2, D2.C, J1.2, J2.2, J3.1, J5.1, Q2.1 (G), R7.2, R19.1, SW1.2 (A), U1.2 (gnd), U2.13 (GND), U2.29, U3.2 (gnd), U4.5 (gnd), U5.1 (GND)
unnamed: Q2.2 (S), R1.1, R19.2
unnamed: R7.1, U1.4 (en_(enable))
unnamed: R5.2, U2.2 (P0.03_A1_D1)
unnamed: R1.2, U2.15 (P0.15_D11_I2S_SD)
unnamed: R8.2, U2.16 (P0.19_D12_I2S_SCK)
unnamed: R6.2, U2.3 (P0.28_A2_D2)
unnamed: R11.2, U2.17 (P1.01_D13_I2S_WS)
unnamed: R16.2, U2.21 (P1.03_D17_SCK1)
unnamed: R12.2, U2.7 (P1.11_D6_TX)
unnamed: R13.2, U2.8 (P1.12_D7_RX)
unnamed: R17.2, U2.9 (P1.13_D8_SCK)
unnamed: R15.2, U2.11 (P1.15_D10_MOSI)

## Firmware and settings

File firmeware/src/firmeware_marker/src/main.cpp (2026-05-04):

#include <Arduino.h>
#include <SD_Logger.h>
#include <SPI_Radio.h>
#include <Sensors.h>
#include <Button_Logic.h>
#include <Buzzer_Logic.h>
#include <System_Check.h>
#include "config.h"

// Objects
SD_Logger SD(Serial1);
SPI_Radio radio(Pins::RADIO_GDO0, Pins::RADIO_CSN);

BME_280 bme(Pins::BME_ADDR, BMEConfig::RETRY_INTERVAL_MS, BMEConfig::TIMEOUT_MS);
Water_Pressure water(Pins::WATER_PRESSURE, WaterConfig::WATER_ADC_RESOLUTION);
Hall_Sensor hall(Pins::HALL_SENSOR);

Buzzer_Logic buzzer(Pins::BUZZER);
Button_Logic button(Pins::BUTTON);

System_Check systemCheck;

// Runtime state
uint32_t counter = 0;
uint32_t lastLog   = 0;
uint32_t lastFlush = 0;

void setup() {
    buzzer.begin();
    buzzer.bootOk();
    delay(500);

    systemCheck.checkSD (SD.begin(9600));
    buzzer.bootOk();
    delay(500);

    systemCheck.checkBME (bme.begin());
    buzzer.bootOk();
    delay(500);

    systemCheck.checkRadio(radio.begin());
    buzzer.bootOk();
    delay(500);

    button.begin();
    buzzer.bootOk();
    delay(500);

    buzzer.begin();
    buzzer.bootOk();
    delay(500);

    // Report
    if (!systemCheck.ok()) {
        char msg[24];
        snprintf(msg, sizeof(msg), "ERR 0x%02X", systemCheck.status());
        buzzer.error(systemCheck.status());
    } else {
        buzzer.bootOk();
    }
}

void loop() {

    // Measure mode management
    button.read();
    // Detect if button pressed show on screen once
    static bool telemetryWasActive = true;
    if (button.telemetryActive() != telemetryWasActive) {
        telemetryWasActive = button.telemetryActive();

        if (button.telemetryActive()) { // ← Handle here the diff mode of measure (test or real mission)
            buzzer.telemetryOn();
        } else {
            buzzer.telemetryOff();
        }
        
        delay(500);
    }

    // Mission logic
    const uint32_t now = millis();

    // to prevent crash we put the buffer data in the SDcard every 10 seconds
    if (now - lastFlush >= Timings::FLUSH_PERIOD_MS) {
        lastFlush = now;

        SD.flush();

        buzzer.sdFlush();
    }
}

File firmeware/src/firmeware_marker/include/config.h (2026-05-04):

#pragma once

#include <cstdint>

namespace Pins {
    // D4 = SDA (I2C) -> BME280
    // D5 = SCL (I2C) -> BME280
    constexpr uint8_t BME_ADDR = 0x76;

    // D6 = TX (Serial1) -> OpenLog RXI
    // D7 = RX (Serial1) -> OpenLog TXO

    // D8 = SCK (SPI) -> Radio
    // D9 = MISO (SPI) -> Radio
    // D10 = MOSI (SPI) -> Radio

    constexpr uint8_t BUTTON = D0;
    constexpr uint8_t BUZZER = D1; // use led pin for now aswell
    constexpr uint8_t WATER_PRESSURE = D2;
    constexpr uint8_t HALL_SENSOR = D3;
    constexpr uint8_t RADIO_GDO0 = D17;
    constexpr uint8_t RADIO_CSN = D19;
}

namespace Timings {
    constexpr uint32_t LOG_PERIOD_MS     = 1000;
    constexpr uint32_t FLUSH_PERIOD_MS   = 10000;
}

namespace WaterConfig {
    constexpr uint16_t WATER_ADC_RESOLUTION = 4096; // 12-bit nRF52840
}

namespace BMEConfig {
    constexpr uint32_t RETRY_INTERVAL_MS = 500;
    constexpr uint32_t TIMEOUT_MS = 1000;
}

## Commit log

2026-04-10 init: starting project
    [main_pcb.kicad_pcb, main_pcb.kicad_sch]
2026-04-16 feature: conso analysis
    [conso.ods]
2026-04-17 feature: PCB cleaner(perfect🤤)
    [main_pcb.kicad_pcb, main_pcb.kicad_sch]
2026-04-19 feature: PCB advancement
    [main_pcb.kicad_pcb, main_pcb.kicad_sch]
2026-04-20 feature: PCB advancement
    [main_pcb.kicad_sch]
2026-05-03 feature: PCB finished finally AAAAAAAAAAAAAAAAAAAAH
    [main_pcb.kicad_pcb, main_pcb.kicad_sch]
2026-05-03 feature: PCB ready to manufacture
    [main_pcb.kicad_pcb]
2026-05-04 feature: PCB ready to manufacture and firmeware start
    [main_pcb.kicad_pcb]
